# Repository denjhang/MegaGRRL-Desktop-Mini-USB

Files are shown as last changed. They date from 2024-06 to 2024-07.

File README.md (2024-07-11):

# MegaGRRL-Desktop-Mini-USB
 I have been using the desktop version of MegaGRRL for 4 years. As my PCB drawing skills improve, I have the confidence to realize all my ideas and changes. This version is based on the Type-C version and includes a lot of practical modifications.Note that for convenience, I only modified the PCB and not the schematic.    
The latest version: MegaGRRL Desktop DJ V0.5.  
It has been hardware verified and can be used.  
## Improvements of Type-C version :  
1. Use CH340C to replace CH340G to save crystal  
2. Use 2SC1815 to replace diode to get full CH340 serial port function (SPFM Lite compatibility)  
3. PCA9634D is difficult to buy, replaced with PCA9634PW.  
4. Use Type-C to replace USB-B.
5. Remaining issue: The solder pad of the 3.5mm headphone jack is too small.  
 ## Details of improvements to my version :   
1. Delete the 7805, 78M33, and other antique LDO step-down chips, as well as the huge heat sink, which are inefficient and generate a lot of heat. I used a newly designed SPFM Lite power supply circuit to replace it.  
2. Use an isolated voltage regulator module such as IB0905/0505S to achieve step-down/regulation, so the PCB currently supports 5V or 9V input, depending on the model of the voltage regulator module. B0905/0505 can be easily obtained on AliExpress. These voltage regulator modules work well on SPFM Lite, with very little power supply noise, which can further improve the sound quality.(Outdated)  
3. Delete MOSFETs such as IRF9530, which are huge and too retro.  
4. Use F0805 to protect the power circuit.  
5. Use a strong PS-22E05 (A04) self-locking switch to replace the original small switch to extend the life of the power button.  
6. All micro switches use white patch 6*6 silicone buttons, which do not require circuit modification and can significantly improve the user experience. The original micro switches made my hands hurt.
7. Because some buyers reported that the main volume potentiometer was easily damaged during transportation, I replaced it with RK097 B10K. RK097 is smaller and more robust, and the entire potentiometer is plastic-sealed, which is more reliable.  
8. Delete the 3296 potentiometer.  
9. In order to make the SN76489 volume adjustable, add an RK097 to adjust its volume, and replace R6/R8 with 47K.  
10. Replace the difficult-to-solder Type-C with Mini-USB.  
11. Restore natalie's silk screen art, obtained by reverse engineering the original desktop motherboard. (Actually not necessary)  
12. Double-layer square hole IC socket ensures good connection and service life. (No need to modify the PCB)  
13. Solder the round hole female header first in RN2 and then insert the resistor (no need to modify the PCB) to facilitate mass production and upload factory firmware.  
14. Add my silk screen art "Denjhang's OSHW"  
15. Optional self-ejecting SD card slot or self-ejecting TF card slot, more flexible to choose the type of memory card, protecting the memory card while further improving the user experience.  
16. Use "Mini560" high efficiency DC-DC step-down module to replace B0905/0505, it works very well so far, supports 9/12V input, and generates almost no heat. Mini560 can be easily purchased at Alex and is cheap.
17. Use the correct PJ-306/3F07 headphone jack package to replace the incorrect package in the Type-C version.
18. Added keyboard connector. Can be used to connect Cherry switches, MegaDrive controllers, wireless remote controls, etc. It can also be connected to the top keyboard of the acrylic case.  
 ## To do  
1. Design and make the acrylic shell, which is done by Xiaohao Studio (completed)  
2. Design a new MegaGRRL-modular motherboard to completely separate the data and analog lines and reduce interference noise. (completed)  
3. USB/DC dual power supply, refer to SPFM Lite circuit (completed)  
4. Compatible with RE:Birth module. (completed)  
5. Add battery interface. (completed)

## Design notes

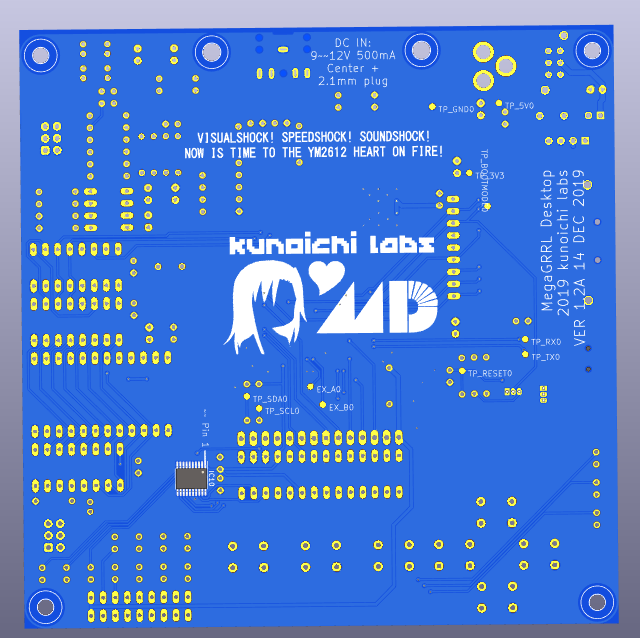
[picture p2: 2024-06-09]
pics/REV.0.4B.png

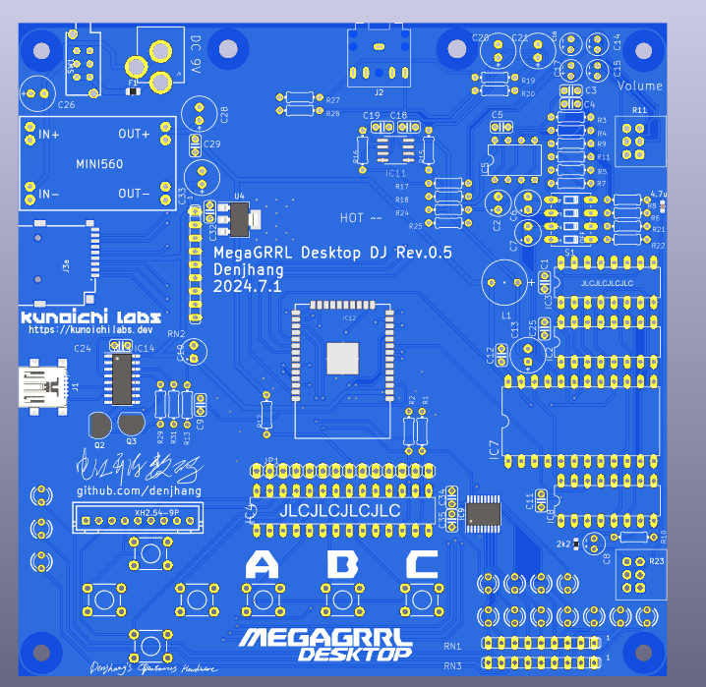
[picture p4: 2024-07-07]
pics/REV.0.5T.png

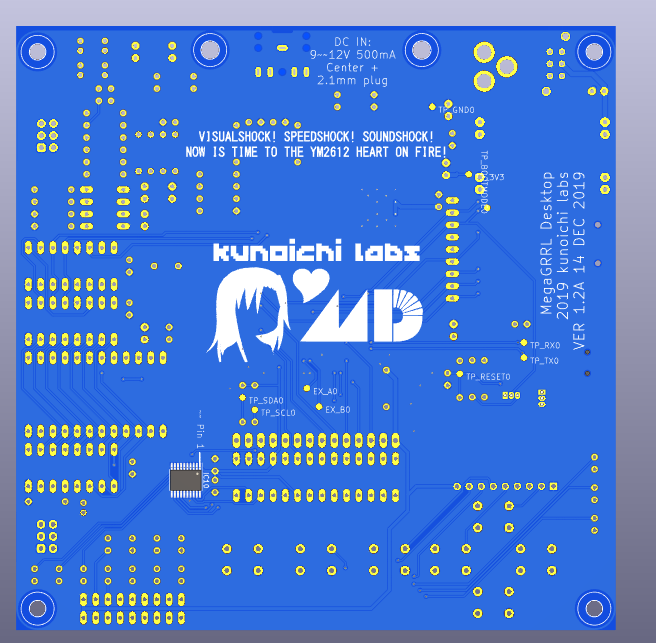
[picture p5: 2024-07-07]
pics/REV.0.5B.png

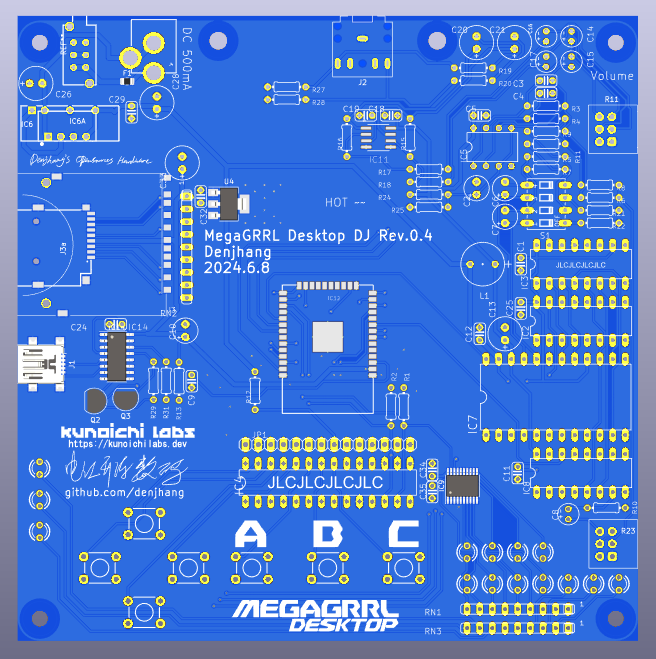
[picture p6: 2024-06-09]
pics/REV.0.4T.png

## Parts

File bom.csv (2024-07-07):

Designator | Footprint | Quantity | Value | LCSC Part #
2k2 | 0603 | 1 | R_0603_1608Metric
4.7u | 0603 | 1 | C_0603_1608Metric
C1, C11, C12, C18, C19, C24, C25, C29, C32, C34, C35, C5, C9 | C025-024X044 | 13 | 0.1uF
C10, C2, C6, C7 | E2,5-5 | 4 | 10uF
C13 | E2,5-7 | 1 | 330uF
C14, C15, C16, C17, C8 | E2-4 | 5 | 1uF
C20, C21, C26, C28, C33 | E2,5-7 | 5 | 100uF
C3, C4 | C025-024X044 | 2 | 120pF
EX_A0, EX_B0, TP_3V3, TP_BOOTMODE0, TP_GND0, TP_RESET0, TP_RX0, TP_SCL0, TP_SDA0, TP_TX0 | B1,27 | 10 | TPB1,27
F1 | 0805 | 1 | Fuse_0805_2012Metric
H3, H4, H7, H8 | 3,2 | 4 | MOUNT-HOLE3.2
H5, H6 | 3,6 | 2 | MOUNT-HOLE3.6
IC10, IC9 | TSSOP-20_4.4x6.5mm_P0.65mm | 2 | PCA9634PW
IC11 | D8 | 1 | TPA6111A2DR
IC12 | ESP-WROOM-32-NO-RF | 1 | ESP-WROOM-32ESP-WROOM-32-NO-RF
IC14 | SOIC-16_3.9x9.9mm_P1.27mm | 1 | CH340C
IC2, IC3 | DIL16 | 2 | 74HCT595N
IC4 | DIL28-3 | 1 | MCP23017SP
IC5 | DIL08 | 1 | NE5532N
IC7 | YM2612 | 1 | YM2612
IC8 | SN76489 | 1 | SN76489
J1 | USB_Mini-B_Lumberg_2486_01_Horizontal | 1 | USB_B_Mini
J2 | Jack_3.5mm_CUI_SJ1-3525N_Horizontal | 1 | 35RAPC4BHN2
J3a | TF-SMD_TF-PUSH | 1 | std:8630a74813a14cdca67e7b05dd5d2bc3
J4 | POWER_JACK_PTH | 1 | POWER_JACK
JP1 | ILI9341_2_4 | 1 | ILI9341_2_4
L1 | RL622_SERIES | 1 | RL622-101K-RC
LED1, LED10, LED11, LED12, LED13, LED14, LED2, LED3, LED4, LED5, LED6, LED7, LED8, LED9 | LED3MM | 14 | LED3MM
Q2, Q3 | TO-92_Inline | 2 | 2SC1815
R1, R10, R2, R21, R22 | 0204_7 | 5 | 2k2
R11_2, R9 | 0204_7 | 2 | 5k6
R11, R23 | Potentiometer_Alps_RK097_Dual_Horizontal | 2 | Potentiometer_Alps_RK097_Dual_Horizontal
R12 | 0204_7 | 1 | 100R
R13, R17, R18, R27, R28, R29, R31 | 0204_7 | 7 | 10k
R15, R16 | 0204_7 | 2 | 15k
R19, R20 | 0204_7 | 2 | 10R
R24, R25 | 0204_7 | 2 | 100k
R3, R4 | 0204_7 | 2 | 82k
R5, R6, R7, R8 | 0204_7 | 4 | 47k
RN1, RN3 | SIL9 | 2 | 1k
RN2 | SIL9 | 1 | 10k
S1 | DIP04S | 1 | DIP04S
SW1 | SW-TH_PS-22E05 | 1 | std:d3d4a25bb1344bd597a3916e4358391c
SWA0, SWB0, SWC0, SWDOWN0, SWLEFT0, SWRIGHT0, SWUP0 | TACTILE_SWITCH_PTH_6.0MM | 7 | MOMENTARY-SWITCH-SPST-PTH-6.0MM
U4 | SOT-223 | 1 | AMS1117-3.3V
XH2.54-9P | CONN-TH_9P-P2.50_ZX-XH2.54-9PZZ | 1 | std:f55dec43d47241219f1ef8a3f0efb8e3

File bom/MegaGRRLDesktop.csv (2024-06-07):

ID | 指示符 | 封装 | 数量 | 名称 | 供应商和参考
1 | R28,R26,R31,R27,R17,R13,R18,R29 | 0204_7 | 8 | 10k
2 | LED9,LED5,LED1,LED2,LED4,LED6,LED3,LED11,LED12,LED13,LED7,LED8,LED14,LED10 | LED3MM | 14 | LED3MM
3 | R23 | S64W | 1 | 100k
4 | R5,R7 | 0204_7 | 2 | 47k
5 | C20,C21,C26,C33,C28 | E2,5-7 | 5 | 100uF
6 | C16,C8,C14,C17,C15 | E2-4 | 5 | 1uF
7 | C5,C35,C9,C29,C32,C1,C24,C18,C11,C25,C19,C12,C30,C31,C34 | C025-024X044 | 15 | 0.1uF
8 | L1 | RL622_SERIES | 1 | RL622-101K-RC
9 | R24,R6,R8,R25 | 0204_7 | 4 | 100k
10 | R9,R11 | 0204_7 | 2 | 5k6
11 | SWC0,SWUP0,SWLEFT0,SWDOWN0,SWA0,SWRIGHT0,SWB0 | TACTILE_SWITCH_PTH_6.0MM | 7 | MOMENTARY-SWITCH-SPST-PTH-6.0MM
12 | S1 | DIP04S | 1 | DIP04S
13 | D3 | DO41-7.6 | 1 | 1N581
14 | R15,R16 | 0204_7 | 2 | 15k
15 | S2 | SW_OS102011MS2QN1 | 1 | OS102011MS2QN1
16 | R19,R20 | 0204_7 | 2 | 10R
17 | IC6 | TO220V | 1 | 78TV
18 | @HOLE5,@HOLE2,@HOLE0,@HOLE4,@HOLE1,@HOLE3 |  | 6
19 | IC2,IC3 | DIL16 | 2 | 74HCT595N
20 | JP1 | ILI9341_2_4 | 1 | ILI9341_2_4
21 | IC9,IC10 | TSSOP-20_4.4x6.5mm_P0.65mm | 2 | PCA9634PW
22 | R21,R1,R22,R10,R2 | 0204_7 | 5 | 2k2
23 | J2 | SWITCHCRAFT_35RAPC4BHN2 | 1 | 35RAPC4BHN2
24 | RN3,RN1 | SIL9 | 2 | 1k
25 | R14 | 3RP_1610G | 1 | 3RP/1610G
26 | C2,C6,C7,C10 | E2,5-5 | 4 | 10uF
27 | IC1 | TO220H | 1 | UA78M33CKCS
28 | RN2 | SIL9 | 1 | 10k
29 | Q3,Q2 | TO-92_Inline | 2 | 2SC1815
30 | IC5 | DIL08 | 1 | NE5532N
31 | R4,R3 | 0204_7 | 2 | 82k
32 | R32,R30 | 0204_7 | 2 | 5.1k
33 | KK1 | 581002B02500G-ISH | 1 | 581002B02500G-ISH
34 | C4,C3 | C025-024X044 | 2 | 120pF
35 | C13 | E2,5-7 | 1 | 330uF
36 | IC7 | YM2612 | 1 | YM2612
37 | J3 | 2041021-3_2 | 1 | 2041021-3
38 | IC8 | SN76489 | 1 | SN76489
39 | Q1 | TO220BV | 1 | IRF9530
40 | IC14 | SOIC-16_3.9x9.9mm_P1.27mm | 1 | CH340C
41 | R12 | 0204_7 | 1 | 100R
42 | J4 | POWER_JACK_PTH | 1 | POWER_JACK
43 | IC11 | D8 | 1 | TPA6111A2DR
44 | J1 | USB_C_Receptacle_HRO_TYPE-C-31-M-12 | 1 | USB_C_Receptacle_USB2.0
45 | IC12 | ESP-WROOM-32-NO-RF | 1 | ESP-WROOM-32ESP-WROOM-32-NO-RF
46 | IC4 | DIL28-3 | 1 | MCP23017SP
47 | H1,H5,H2,H6 | 3,6 | 4 | MOUNT-HOLE3.6
48 | TP_SCL0,TP_3V3,TP_RX0,TP_VIN_SW0,TP_GND0,EX_A0,TP_VIN0,TP_BOOTMODE0,TP_TX0,EX_B0,TP_RESET0,TP_5V0,TP_SDA0 | B1,27 | 13 | TPB1,27
49 | H3,H8,H4,H7 | 3,2 | 4 | MOUNT-HOLE3.2

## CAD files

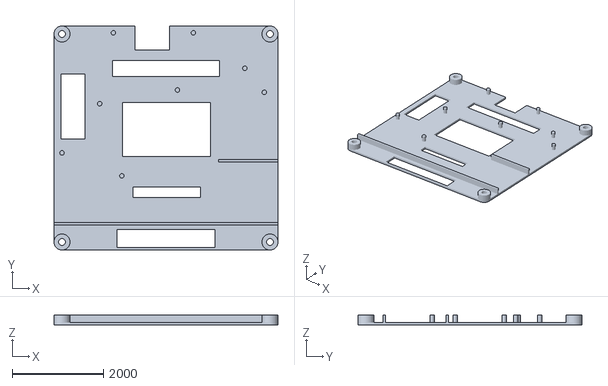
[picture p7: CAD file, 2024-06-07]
mgd_base.stl
4900.0 x 4900.0 x 220.0

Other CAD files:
Silk Screen Art/ART_2024-06-072 5.0.DWG
mgd_base.scad

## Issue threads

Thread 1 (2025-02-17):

The sound issue

hualazimo7, 2025-02-17:
Hello, I have built one last week, using YM2612.
But the sound is weird, sounds like ZZZZZ. It's definitly a broken sound.

denjhang, 2025-02-17:
You probably didn't adjust the dip switches. All on the left will be compatible with the YM2612, all on the right will be compatible with the YM3438.

denjhang, 2025-02-17:
You can upload a photo of your MegaGRRL and I'll double check it.😄

hualazimo7, 2025-02-17:
原来是国内的大佬，失敬失敬。我是在原本作者的基础上换了一些芯片的封装，比如AHCT595我用的TSSOP版。再就是一些电容电阻我改成贴片的了。（因为手头刚好有）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

denjhang, 2025-02-17:
你做的不是我改进的mini usb 版本，因此不要问我。😅

denjhang, 2025-02-17:
你难道没有看readme写的改进吗？先看清楚。

hualazimo7, 2025-02-17:
好的，不好意思，我学习下先。

denjhang, 2025-02-17:
https://discord.gg/wjS39pcF
有问题请进MegaGRRL社区讨论

denjhang, 2025-02-17:
或者加qq群:
930442674

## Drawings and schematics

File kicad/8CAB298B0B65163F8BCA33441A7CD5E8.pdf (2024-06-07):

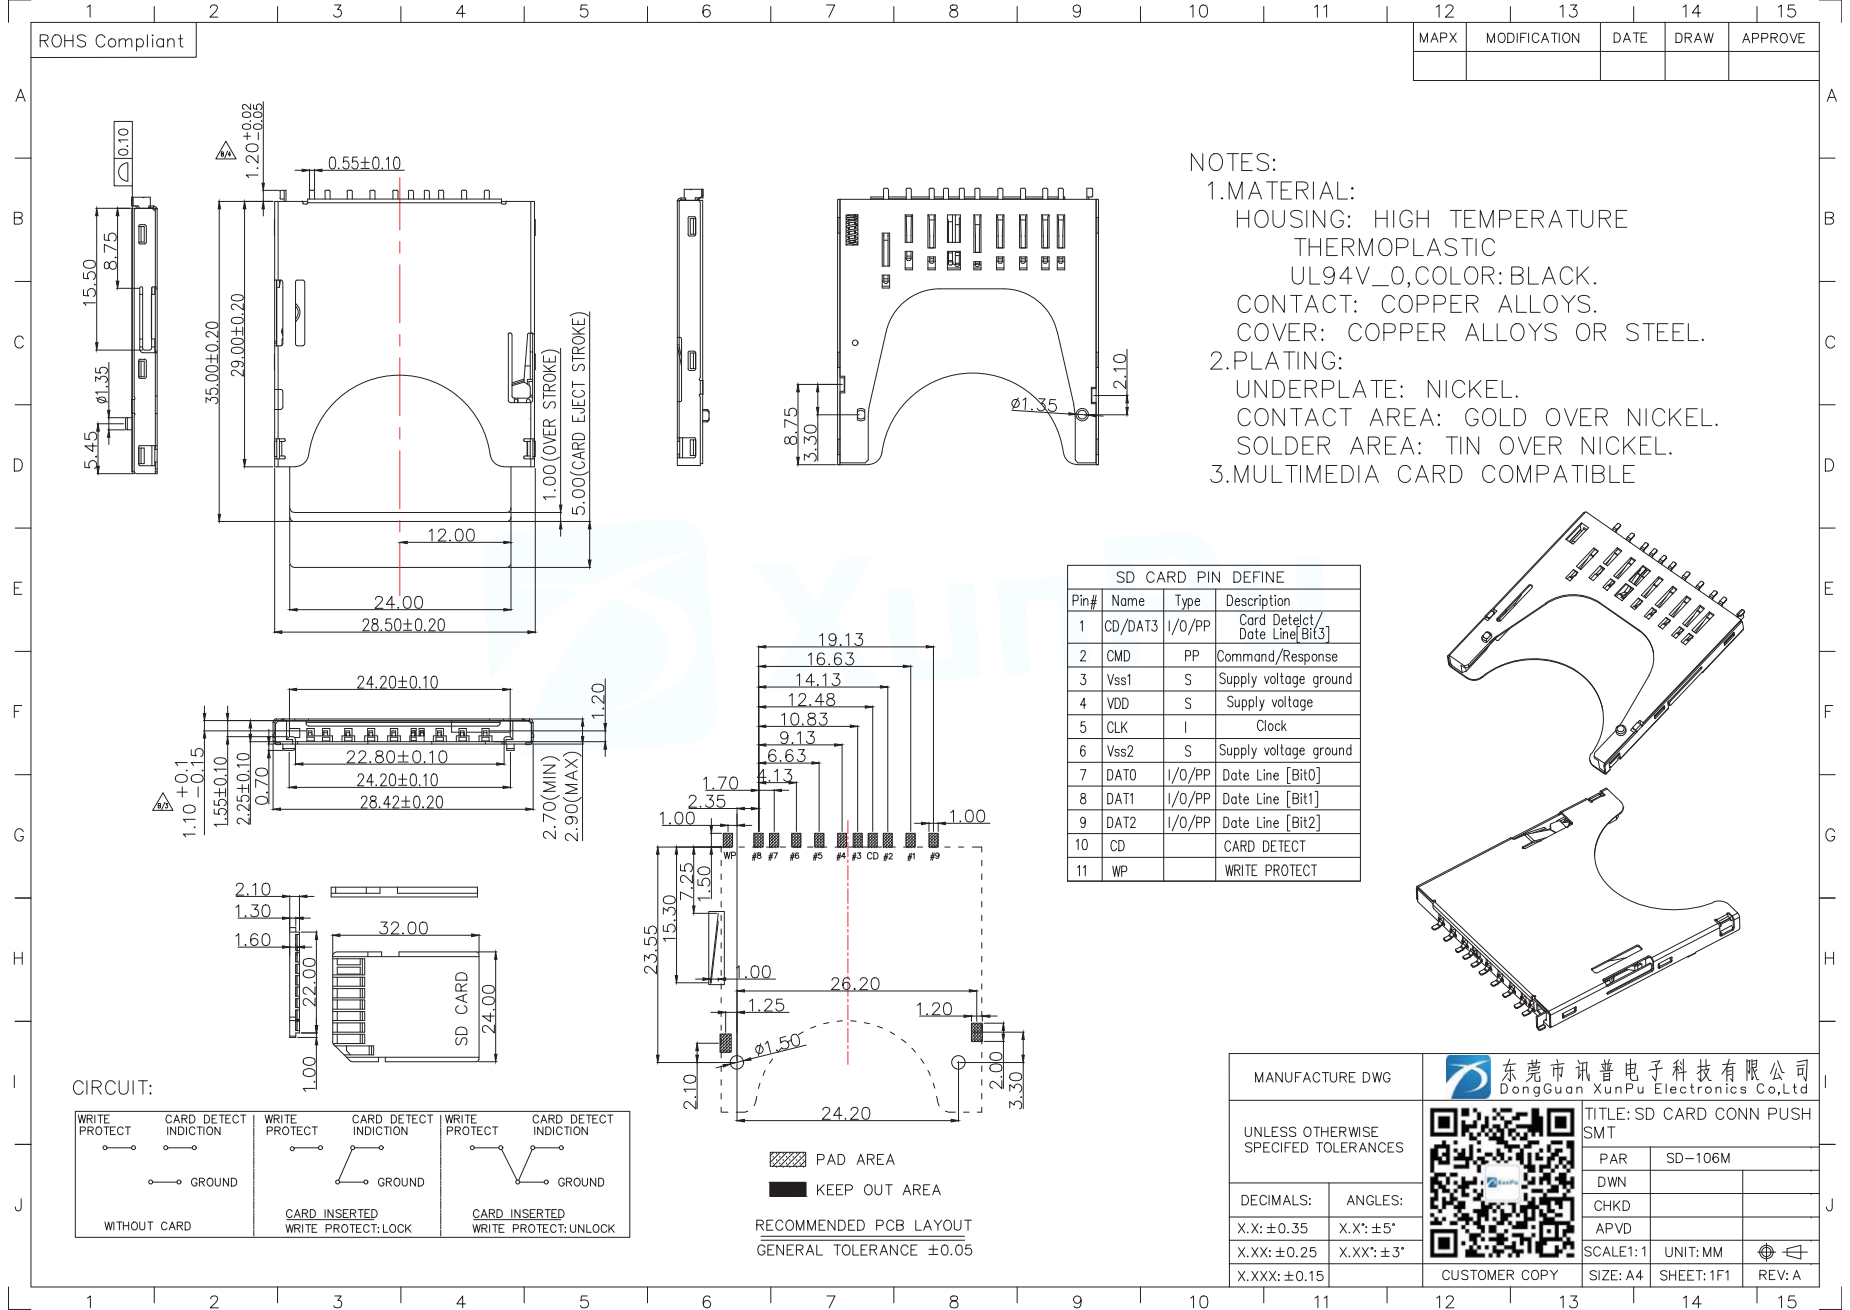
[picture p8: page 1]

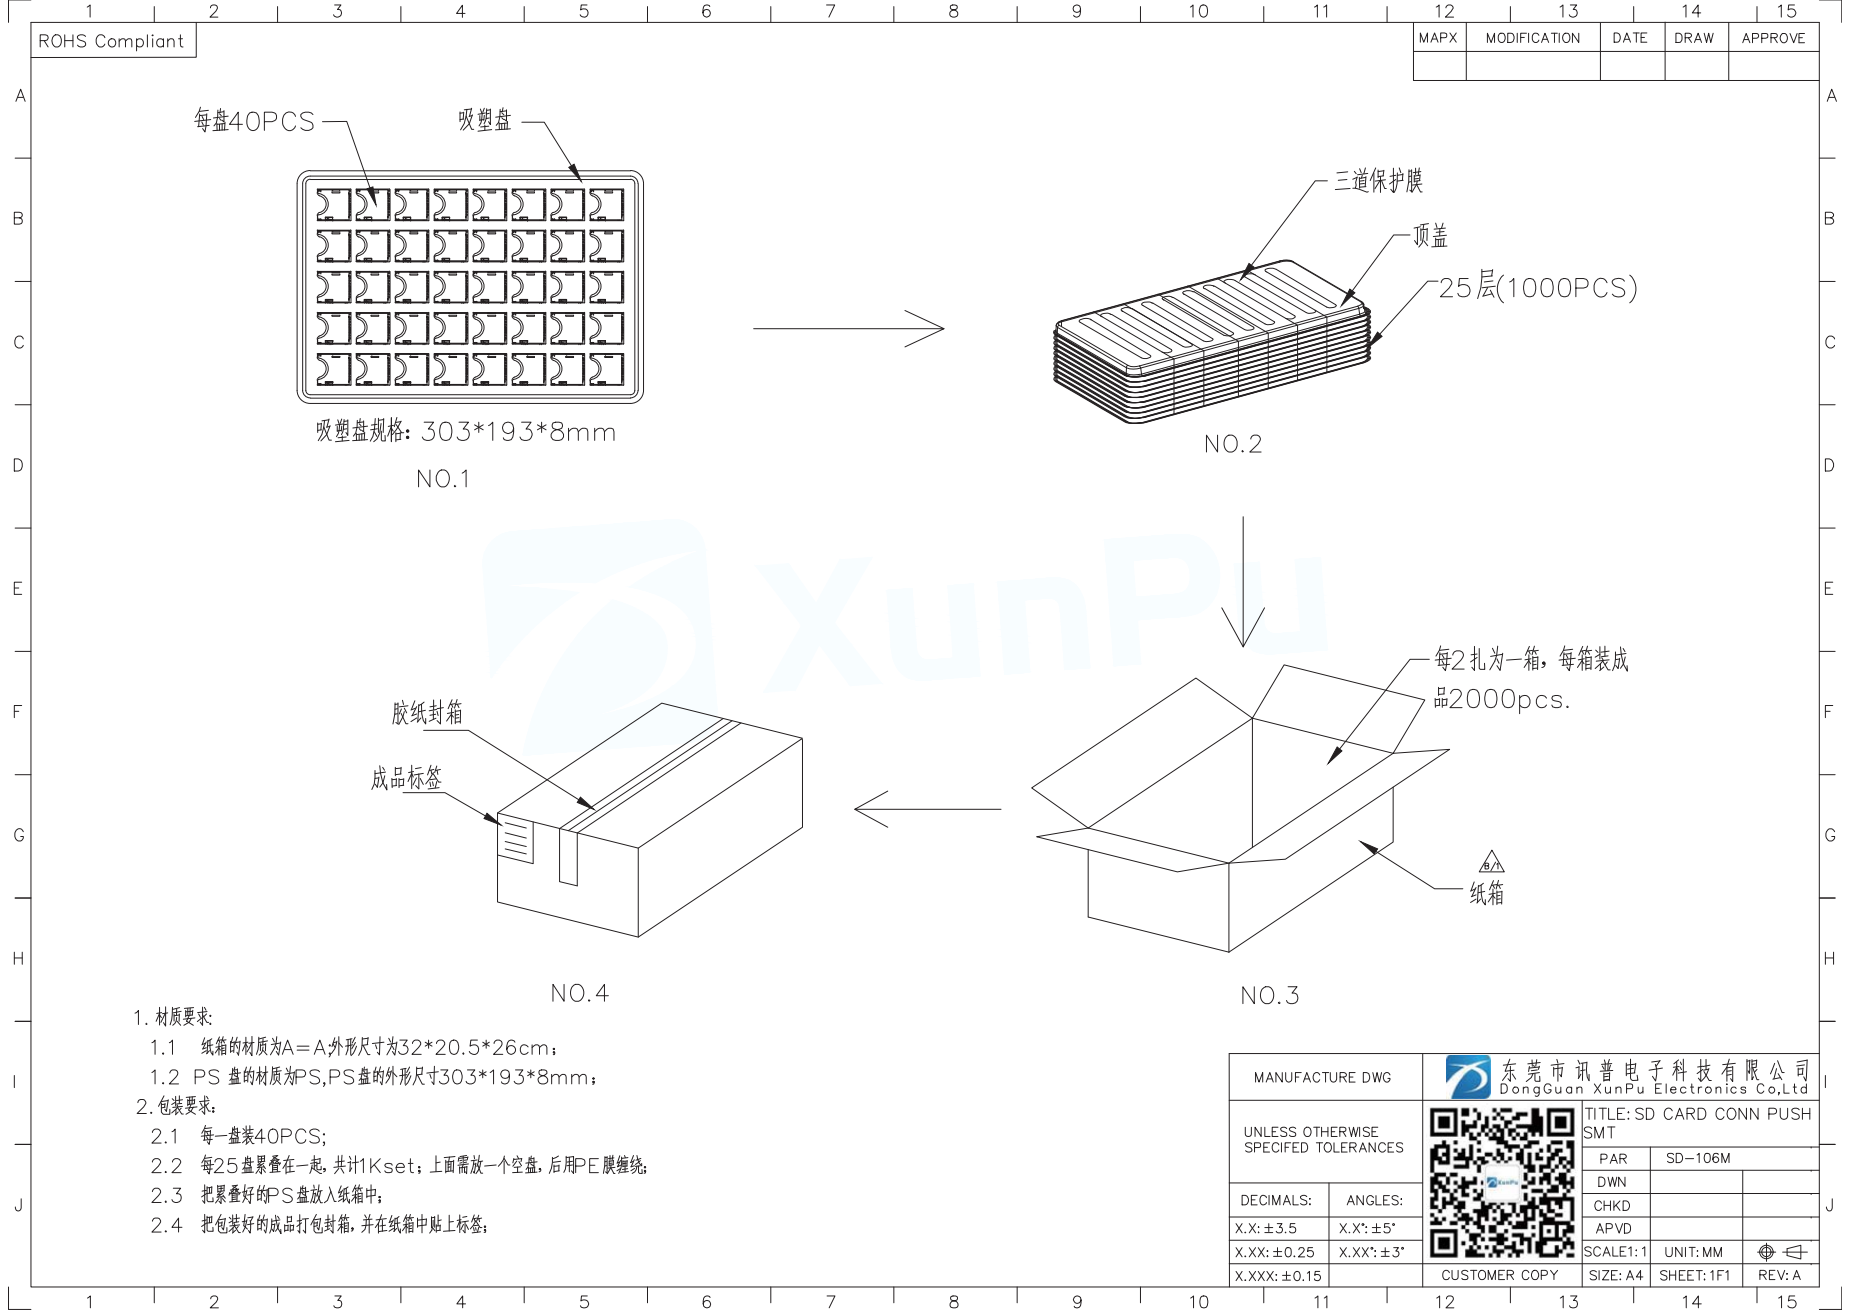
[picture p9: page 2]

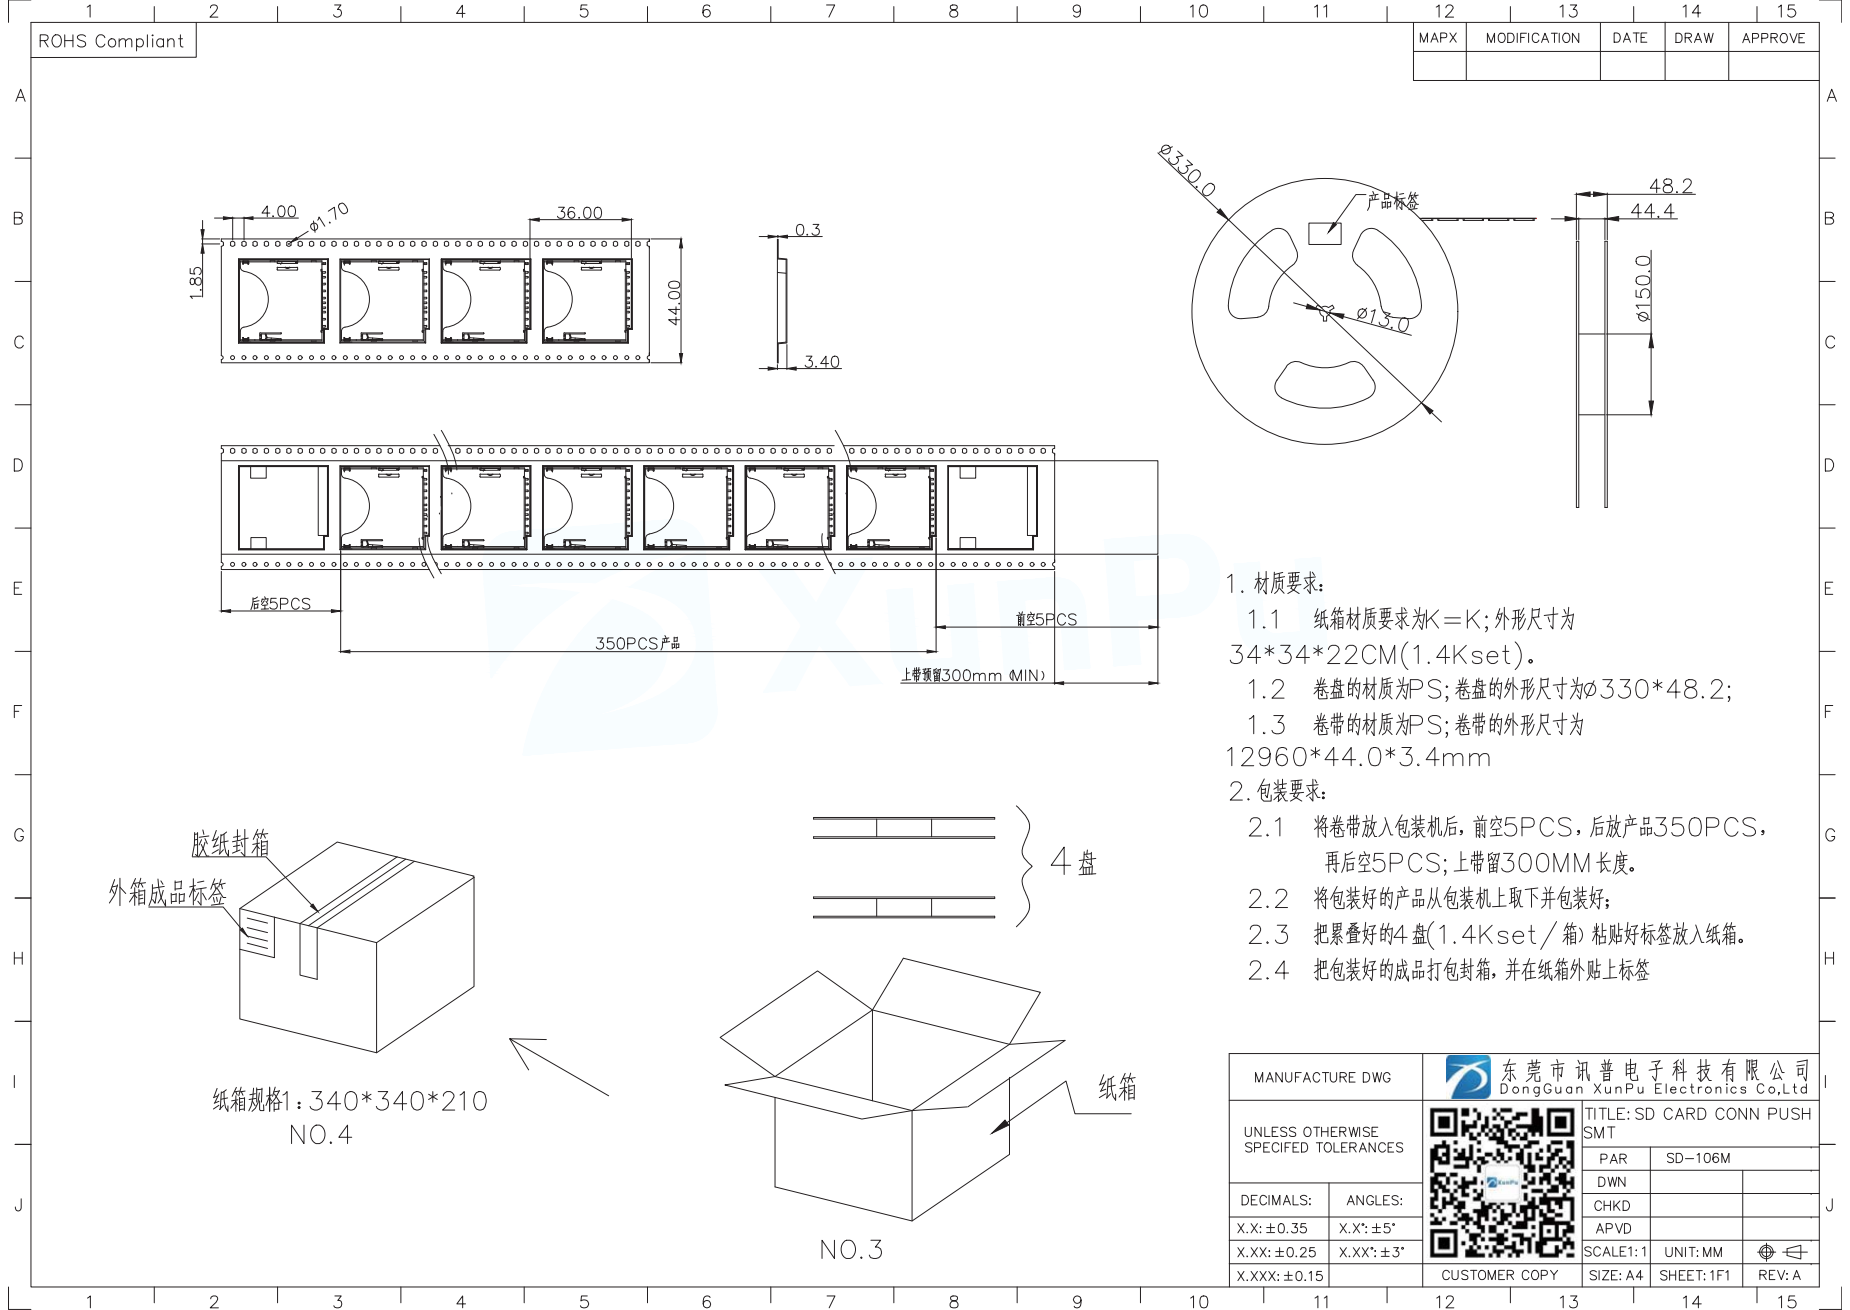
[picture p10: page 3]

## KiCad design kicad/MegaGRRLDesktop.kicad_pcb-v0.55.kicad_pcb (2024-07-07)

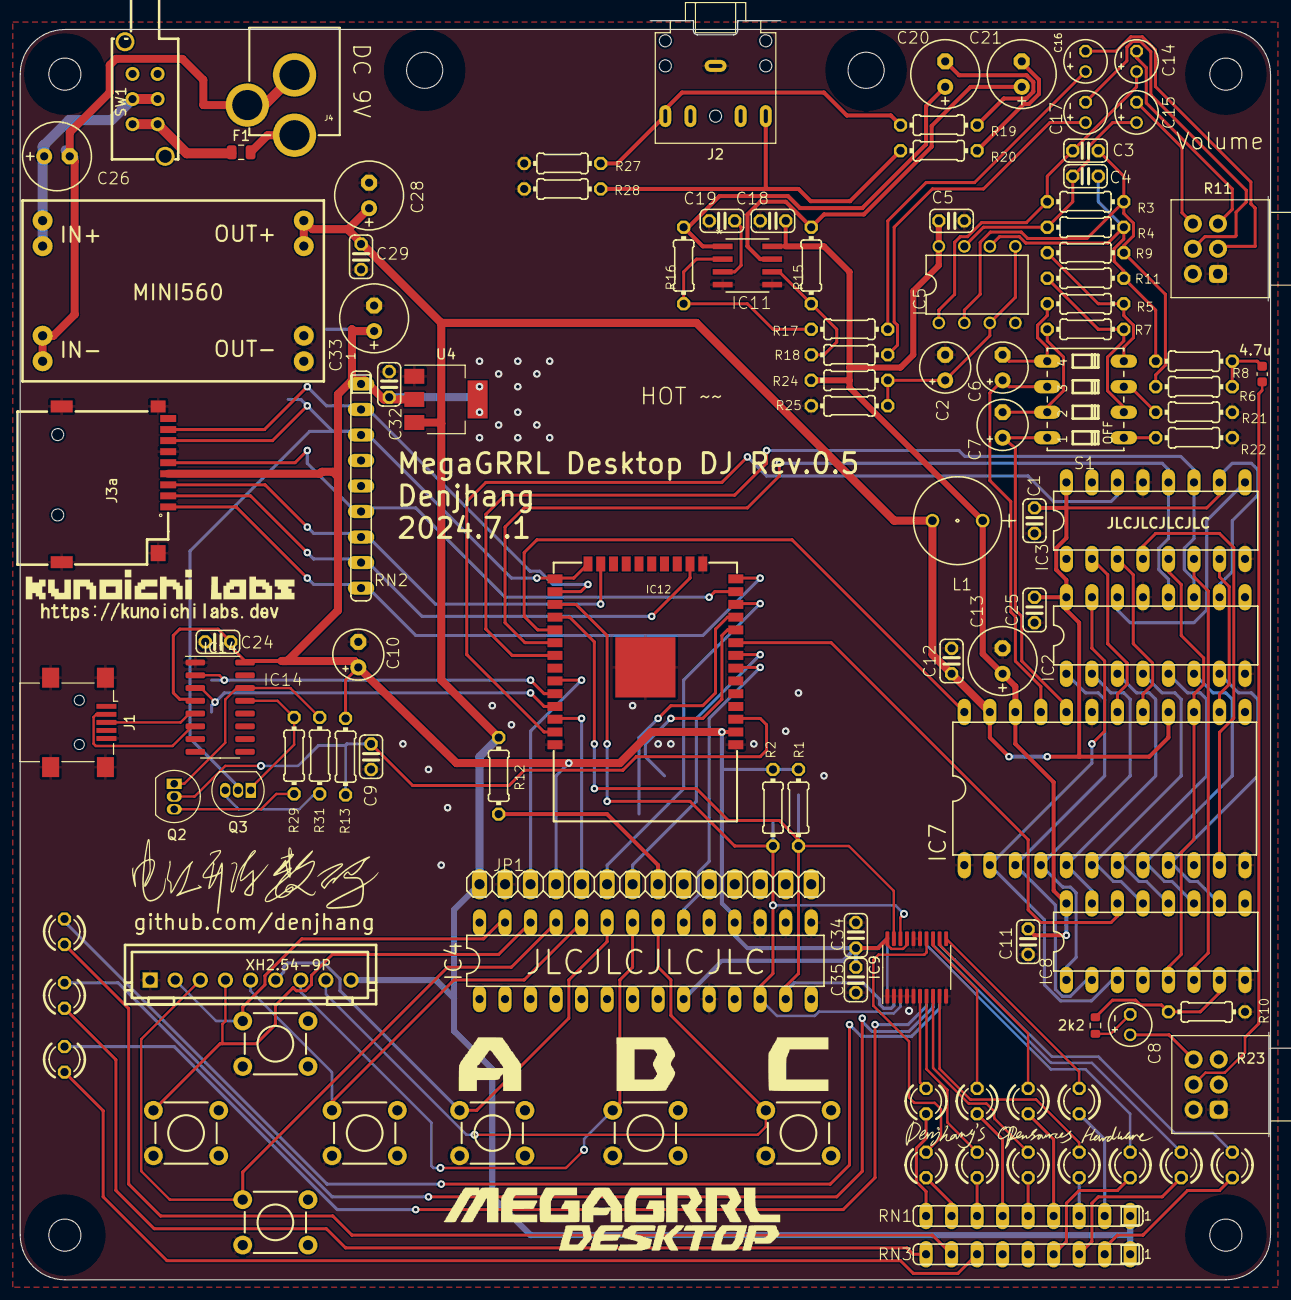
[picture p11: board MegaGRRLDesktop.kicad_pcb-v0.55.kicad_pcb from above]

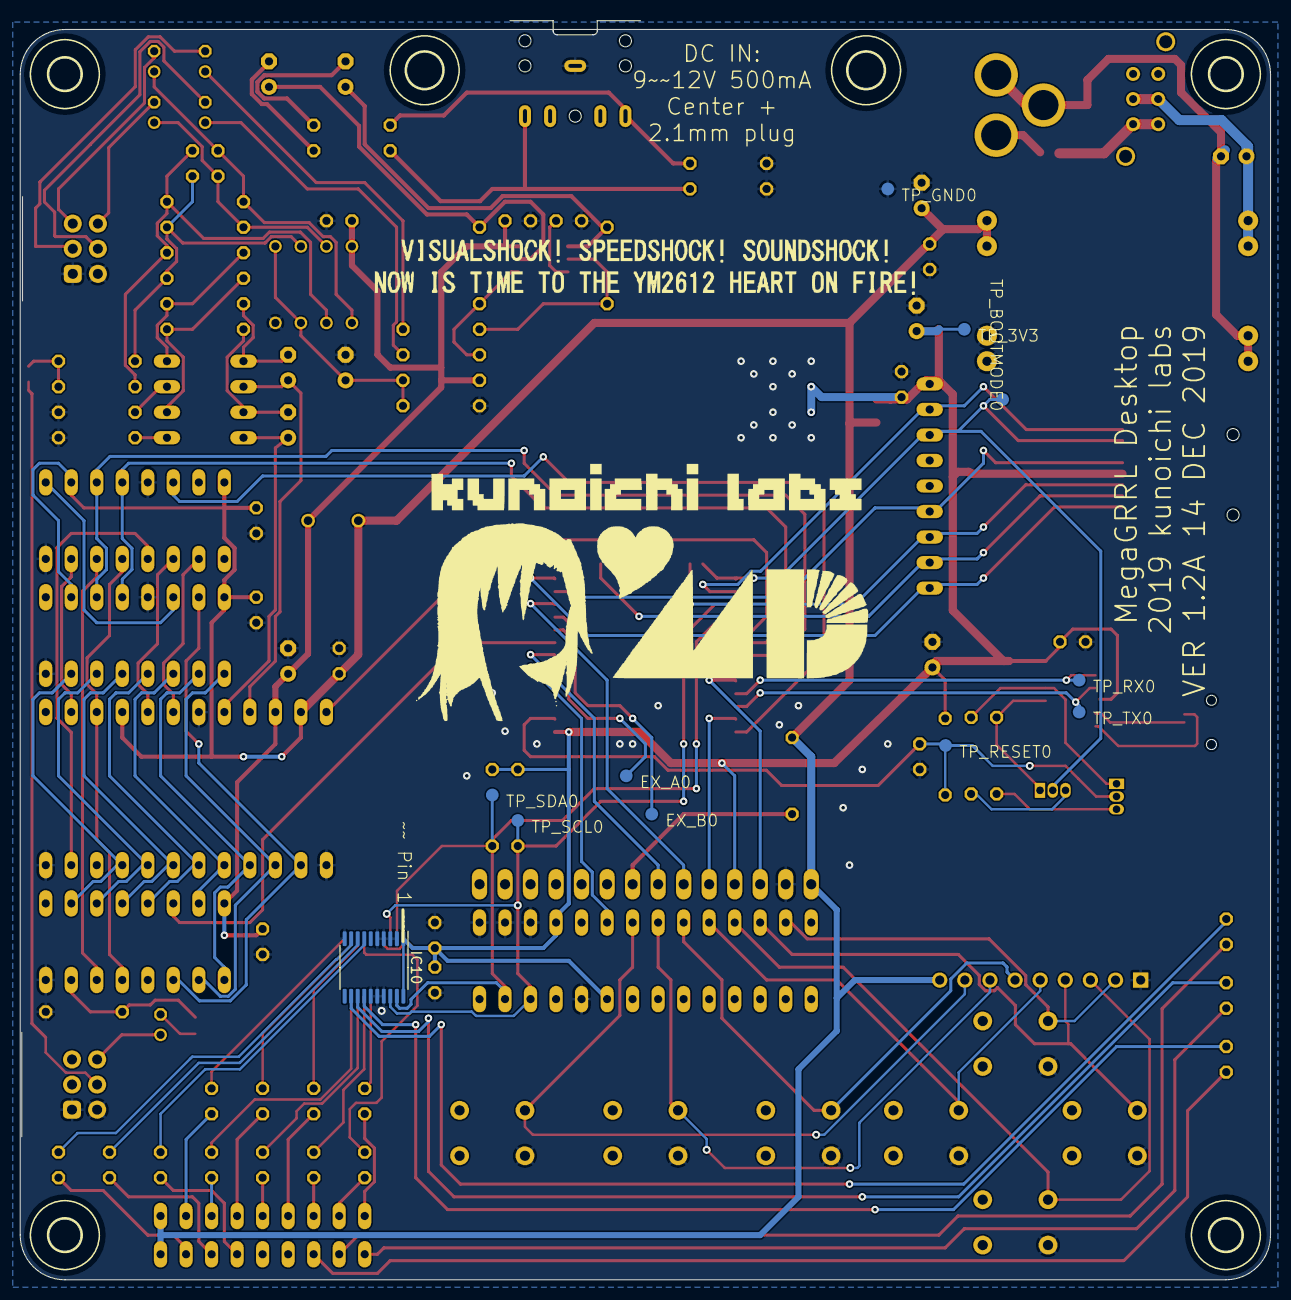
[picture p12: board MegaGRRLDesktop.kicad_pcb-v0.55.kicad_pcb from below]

Board: 2 copper layers, 124.5 x 125.3 mm, 125 parts (17 on the bottom side), 121 nets.

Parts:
2k2: R_0603_1608Metric
4.7u: C_0603_1608Metric
C1, C5, C9, C11, C12, C18, C19, C24, C25, C29, C32, C34, C35: 0.1uF; C025-024X044
C2, C6, C7, C10: 10uF; E2,5-5
C3, C4: 120pF; C025-024X044
C8, C14, C15, C16, C17: 1uF; E2-4
C13: 330uF; E2,5-7
C20, C21, C26, C28, C33: 100uF; E2,5-7
EX_A0: B1,27
EX_B0: B1,27
F1: Fuse_0805_2012Metric
H3, H4, H7, H8: MOUNT-HOLE3.2; 3,2
H5, H6: MOUNT-HOLE3.6; 3,6
IC2, IC3: 74HCT595N; DIL16
IC4: MCP23017SP; DIL28-3
IC5: NE5532N; DIL08
IC7: YM2612
IC8: SN76489
IC9, IC10: PCA9634PW; TSSOP-20_4.4x6.5mm_P0.65mm
IC11: TPA6111A2DR; D8
IC12: ESP-WROOM-32ESP-WROOM-32-NO-RF; ESP-WROOM-32-NO-RF
IC14: CH340C; SOIC-16_3.9x9.9mm_P1.27mm
J1: USB_B_Mini; USB_Mini-B_Lumberg_2486_01_Horizontal
J2: 35RAPC4BHN2; Jack_3.5mm_CUI_SJ1-3525N_Horizontal
J3a: std:8630a74813a14cdca67e7b05dd5d2bc3; TF-SMD_TF-PUSH
J4: POWER_JACK; POWER_JACK_PTH
JP1: ILI9341_2_4
L1: RL622-101K-RC; RL622_SERIES
LED1, LED2, LED3, LED4, LED5, LED6, LED7, LED8, LED9, LED10, LED11, LED12, LED13, LED14: LED3MM
Q2, Q3: 2SC1815; TO-92_Inline
R1, R2, R10, R21, R22: 2k2; 0204_7
R3, R4: 82k; 0204_7
R5, R7: 47k; 0204_7
R6, R8: 47K; 0204_7
R9, R11: 5k6; 0204_7
R11#2, R23: Potentiometer_Alps_RK097_Dual_Horizontal
R12: 100R; 0204_7
R13, R17, R18, R27, R28, R29, R31: 10k; 0204_7
R15, R16: 15k; 0204_7
R19, R20: 10R; 0204_7
R24, R25: 100k; 0204_7
RN1, RN3: 1k; SIL9
RN2: 10k; SIL9
S1: DIP04S
SW1: std:d3d4a25bb1344bd597a3916e4358391c; SW-TH_PS-22E05
SWA0: MOMENTARY-SWITCH-SPST-PTH-6.0MM; TACTILE_SWITCH_PTH_6.0MM
SWB0: MOMENTARY-SWITCH-SPST-PTH-6.0MM; TACTILE_SWITCH_PTH_6.0MM
SWC0: MOMENTARY-SWITCH-SPST-PTH-6.0MM; TACTILE_SWITCH_PTH_6.0MM
SWDOWN0: MOMENTARY-SWITCH-SPST-PTH-6.0MM; TACTILE_SWITCH_PTH_6.0MM
SWLEFT0: MOMENTARY-SWITCH-SPST-PTH-6.0MM; TACTILE_SWITCH_PTH_6.0MM
SWRIGHT0: MOMENTARY-SWITCH-SPST-PTH-6.0MM; TACTILE_SWITCH_PTH_6.0MM
SWUP0: MOMENTARY-SWITCH-SPST-PTH-6.0MM; TACTILE_SWITCH_PTH_6.0MM
TP_3V3: B1,27
TP_BOOTMODE0: B1,27
TP_GND0: B1,27
TP_RESET0: B1,27
TP_RX0: B1,27
TP_SCL0: B1,27
TP_SDA0: B1,27
TP_TX0: B1,27
U4: AMS1117-3.3V; SOT-223
XH2.54-9P: std:f55dec43d47241219f1ef8a3f0efb8e3; CONN-TH_9P-P2.50_ZX-XH2.54-9PZZ

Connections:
+3V3: C10.+, C24.1, C32.1, C33.+, C34.1, C35.1, IC4.9 (VDD), IC4.18 (~RESET), IC9.17 (A6), IC9.20 (VDD), IC10.1 (A0), IC10.20 (VDD), IC12.2 (3V3), IC14.4 (V3), IC14.16 (VCC), J3a.4, JP1.4, R1.2, R2.2, R13.2, RN2.1, TP_3V3.TP, U4.2 (OUT), U4.4 (TAB)
+5V: C1.1, C12.1, C25.1, C28.+, C29.1, IC2.10 (SCL), IC2.16 (VCC), IC3.10 (SCL), IC3.16 (VCC), IC7./RD, IC7.VCC, JP1.1, L1.2, R12.2, RN1.1, RN3.1, U4.3 (IN), XH2.54-9P.9
+5V/2: C5.1, C11.1, C13.+, C18.1, IC5.8 (V+), IC7.AVCC, IC8.VCC, IC11.8 (VDD), L1.1, R24.2
+12V: C26.+, SW1.3, SW1.4
/Audio/AUDIO_LINEL: C16.+, R17.1
/Audio/AUDIO_LINER: C17.+, R18.1
/Keys/KEY_A: IC4.23 (GPA2), SWA0.1, XH2.54-9P.6
/Keys/KEY_B: IC4.22 (GPA1), SWB0.1, XH2.54-9P.7
/Keys/KEY_C: IC4.21 (GPA0), SWC0.1, XH2.54-9P.8
/Keys/KEY_DOWN: IC4.25 (GPA4), SWDOWN0.1, XH2.54-9P.3
/Keys/KEY_LEFT: IC4.26 (GPA5), SWLEFT0.1, XH2.54-9P.4
/Keys/KEY_RIGHT: IC4.24 (GPA3), SWRIGHT0.1, XH2.54-9P.5
/Keys/KEY_UP: IC4.27 (GPA6), SWUP0.1, XH2.54-9P.2
/LED drivers/FM1: IC9.14 (LED7), LED1.K (C)
/LED drivers/FM1N: LED1.A, RN1.8
/LED drivers/FM2: IC9.7 (LED1), LED2.K (C)
/LED drivers/FM2N: LED2.A, RN1.7
/LED drivers/FM3: IC9.8 (LED2), LED3.K (C)
/LED drivers/FM3N: LED3.A, RN1.5
/LED drivers/FM4: IC9.9 (LED3), LED4.K (C)
/LED drivers/FM4N: LED4.A, RN1.3
/LED drivers/FM5: IC10.7 (LED1), LED5.K (C)
/LED drivers/FM5N: LED5.A, RN3.4
/LED drivers/FM6: IC10.8 (LED2), LED6.K (C)
/LED drivers/FM6N: LED6.A, RN3.3
/LED drivers/FMS: IC10.9 (LED3), LED7.K (C)
/LED drivers/FMSN: LED7.A, RN3.2
/LED drivers/PSG1: IC9.6 (LED0), LED8.K (C)
/LED drivers/PSG1N: LED8.A, RN1.9
/LED drivers/PSG2: IC9.13 (LED6), LED9.K (C)
/LED drivers/PSG2N: LED9.A, RN1.6
/LED drivers/PSG3: IC9.12 (LED5), LED10.K (C)
/LED drivers/PSG3N: LED10.A, RN1.4
/LED drivers/PSGS: IC9.11 (LED4), LED11.K (C)
/LED drivers/PSGSN: LED11.A, RN1.2
/LED drivers/USERA: IC10.12 (LED5), LED12.K (C)
/LED drivers/USERAN: LED12.A, RN3.8
/LED drivers/USERB: IC10.13 (LED6), LED13.K (C)
/LED drivers/USERBN: LED13.A, RN3.9
/LED drivers/USERC: IC10.14 (LED7), LED14.K (C)
/LED drivers/USERCN: LED14.A, RN3.7
/MCU & interface/ESP32_RESET: C9.1, IC12.3 (EN), Q2.2 (C), R13.1, TP_RESET0.TP
/MCU & interface/LCD_CLK: IC12.8 (IO32), JP1.7
/MCU & interface/LCD_DC: IC12.36 (IO22), JP1.5
/MCU & interface/LCD_MOSI: IC12.12 (IO27), JP1.6
/MCU & interface/LCD_/CS: IC12.33 (IO21), JP1.3
/MCU & interface/RXD: IC12.34 (RXD0), IC14.2 (TXD), TP_RX0.TP
/MCU & interface/SD_CLK: IC12.13 (IO14), J3a.5, RN2.6
/MCU & interface/SD_CMD: IC12.23 (IO15), J3a.3, RN2.7
/MCU & interface/SD_D0: IC12.24 (IO2), IC12.25 (IO0), J3a.7, Q3.2 (C), RN2.3, TP_BOOTMODE0.TP
/MCU & interface/SD_D1: IC12.26 (IO4), J3a.8, RN2.2
/MCU & interface/SD_D2: IC12.14 (IO12), J3a.1, RN2.9
/MCU & interface/SD_D3: IC12.16 (IO13), J3a.2, RN2.8
/MCU & interface/TXD: IC12.35 (TXD0), IC14.3 (RXD), TP_TX0.TP
/Sound chips & bus/A0: IC3.3 (QD), IC7.A0
/Sound chips & bus/A1: IC3.2 (QC), IC7.A1
/Sound chips & bus/D0: IC2.15 (QA), IC7.D0, IC8.D7
/Sound chips & bus/D1: IC2.1 (QB), IC7.D1, IC8.D6
/Sound chips & bus/D2: IC2.2 (QC), IC7.D2, IC8.D5
/Sound chips & bus/D3: IC2.3 (QD), IC7.D3, IC8.D4
/Sound chips & bus/D4: IC2.4 (QE), IC7.D4, IC8.D3
/Sound chips & bus/D5: IC2.5 (QF), IC7.D5, IC8.D2
/Sound chips & bus/D6: IC2.6 (QG), IC7.D6, IC8.D1
/Sound chips & bus/D7: IC2.7 (QH), IC7.D7, IC8.D0
/Sound chips & bus//CS_FM: IC3.7 (QH), IC7./CS
/Sound chips & bus//CS_PSG: IC3.6 (QG), IC8./OE
/Sound chips & bus//IC: IC3.4 (QE), IC7./IC
/Sound chips & bus//WR: IC3.5 (QF), IC7./WR, IC8./WE
AUDIO_FML: C6.+, IC7.MOL, S1.6 (2)
AUDIO_FMR: C7.+, IC7.MOR, S1.8 (2)
AUDIO_PSG: 2k2.1, IC8.SND_OUT, R10.1
AUDIO_PSG2: 2k2.2, C8.-
CLK_FM: IC7.M, IC12.29 (IO5)
CLK_PSG: IC8.CLOCK, IC12.9 (IO33)
DC-IN: F1.1, SW1.1, SW1.2
GND: C1.2, C2.-, C5.2, C9.2, C10.-, C11.2, C12.2, C13.-, C18.2, C19.2, C24.2, C25.2, C28.-, C29.2, C32.2, C33.-, C34.2, C35.2, IC2.8 (GND), IC2.13 (G), IC3.8 (GND), IC3.13 (G), IC4.10 (VSS), IC4.15 (A0), IC4.16 (A1), IC4.17 (A2), IC5.4 (V-), IC7.AGND, IC7.GND@1, IC7.GND@2, IC8.GND, IC9.1 (A0), IC9.2 (A1), IC9.3 (A2), IC9.4 (A3), IC9.5 (A4), IC9.10 (VSS), IC9.15 (OE), IC9.16 (A5), IC10.2 (A1), IC10.3 (A2), IC10.4 (A3), IC10.5 (A4), IC10.10 (VSS), IC10.15 (OE), IC10.16 (A5), IC10.17 (A6), IC11.4 (GND), IC11.5 (SHUTDOWN), IC12.1 (GND@1), IC12.15 (GND@15), IC12.38 (GND@38), IC12.GND, IC14.1 (GND), J1.5 (GND), J1.6 (Shield), J2.S, J3a.6, J3a.10, J3a.11, J3a.12, J3a.13, JP1.2, R10.2, R11#2.1, R11#2.4, R21.1, R22.1, R23.1, R23.4, R25.1, R27.1, R28.1, SWA0.3 (2), SWB0.3 (2), SWC0.3 (2), SWDOWN0.3 (2), SWLEFT0.3 (2), SWRIGHT0.3 (2), SWUP0.3 (2), TP_GND0.TP, U4.1 (GND), XH2.54-9P.1
GND-IN: C26.-, J4.GND, J4.GNDBREAK
KEY_INT: IC4.20 (INTA), IC12.7 (IO35)
unnamed: C8.+, R23.6
unnamed: C20.-, R19.1
unnamed: C21.-, R20.1
unnamed: F1.2, J4.PWR
unnamed: IC2.14 (SER), IC3.9 (QH*)
unnamed: C3.1, IC5.2 (-IN), R3.2, R6.1, R9.1
unnamed: C3.2, C14.+, IC5.1 (OUT), R3.1
unnamed: C4.1, IC5.6 (-IN), R4.2, R8.1, R11.1
unnamed: C4.2, C15.+, IC5.7 (OUT), R4.1
unnamed: C19.1, IC11.3 (BYPASS)
unnamed: IC11.2 (IN1-), R16.1, R17.2
unnamed: IC11.6 (IN2-), R15.1, R18.2
unnamed: C20.+, IC11.1 (VO1), R16.2
unnamed: C21.+, IC11.7 (VO2), R15.2
unnamed: EX_A0.TP, IC12.10 (IO25)
unnamed: EX_B0.TP, IC12.11 (IO26)
unnamed: IC14.5 (UD+), J1.3 (D+)
unnamed: IC14.6 (UD-), J1.2 (D-)
unnamed: IC14.13 (~DTR), Q3.1 (E), R29.1
unnamed: IC14.14 (~RTS), Q2.1 (E), R31.1
unnamed: J2.R, R20.2, R28.2
unnamed: J2.T, R19.2, R27.2
unnamed: JP1.8, R12.1
unnamed: Q2.3 (B), R29.2
unnamed: Q3.3 (B), R31.2
unnamed: C14.-, R11#2.3
unnamed: C16.-, R11#2.2
unnamed: C15.-, R11#2.6
unnamed: C17.-, R11#2.5
unnamed: R22.2, S1.1
unnamed: 4.7u.2, R6.2, R8.2
unnamed: R7.1, R11.2, S1.2 (1)
unnamed: C7.-, R7.2, S1.7 (2)
unnamed: R21.2, S1.3 (1)
unnamed: R5.1, R9.2, S1.4 (1)
unnamed: C6.-, R5.2, S1.5 (2)
PSG_MIX1: 4.7u.1, R23.5
SCL: IC4.12 (SCL), IC9.18 (SCL), IC10.18 (SCL), IC12.27 (IO16), R2.1, TP_SCL0.TP
SDA: IC4.13 (SDA), IC9.19 (SDA), IC10.19 (SDA), IC12.28 (IO17), R1.1, TP_SDA0.TP
SHCLK: IC2.11 (SCK), IC3.11 (SCK), IC12.31 (IO19)
SHDATA: IC3.14 (SER), IC12.37 (IO23)
SHSTO: IC2.12 (RCK), IC3.12 (RCK), IC12.30 (IO18)
VBIAS: C2.+, IC5.3 (+IN), IC5.5 (+IN), R24.1, R25.2
